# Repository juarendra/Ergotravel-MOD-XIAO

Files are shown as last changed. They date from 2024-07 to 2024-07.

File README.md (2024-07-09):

# Ergotravel-MOD-XIAO
This is MOD of Ergotravel, the normal redox for qmk and wired. This mod is for mod ergotravel to become wireless using ZMK Firmware, and add Swith and Battery socket

## Spesification
- Controller using Seeed Studio XIAO nRF52840 
- ZMK Firmware
- Battery Socket and Switch
- BLE Support
- Hotswap Switch
- 54 Keys

## Preview Hardware

<p align="center">
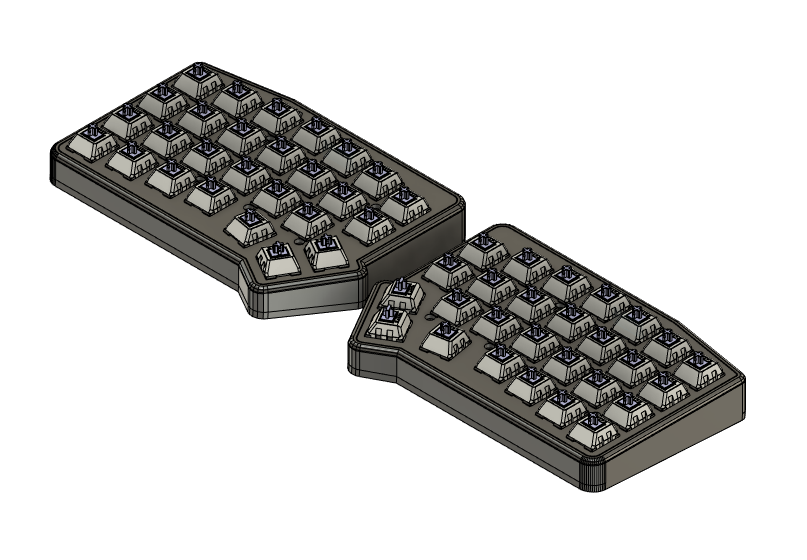
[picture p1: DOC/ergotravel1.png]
  
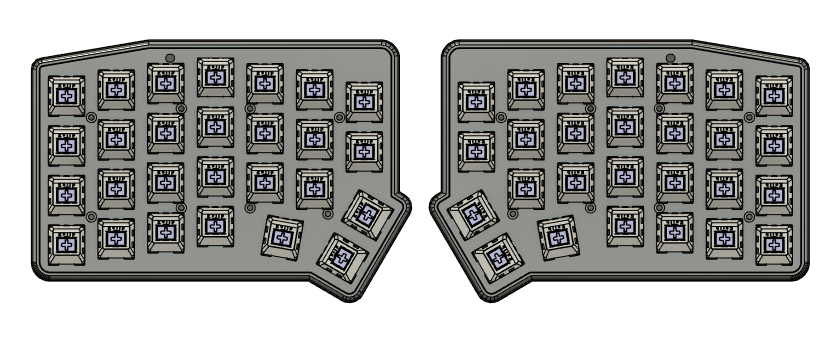
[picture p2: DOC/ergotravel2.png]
  
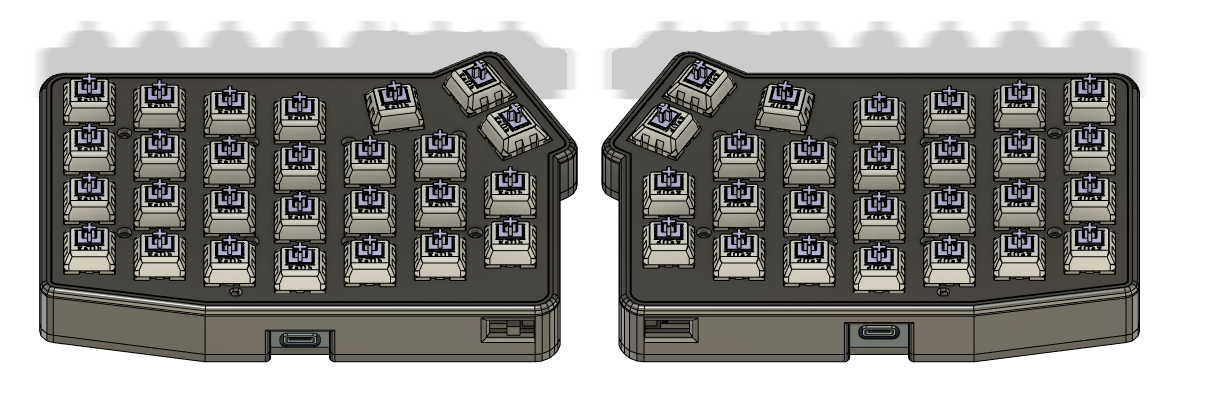
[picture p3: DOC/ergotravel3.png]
  
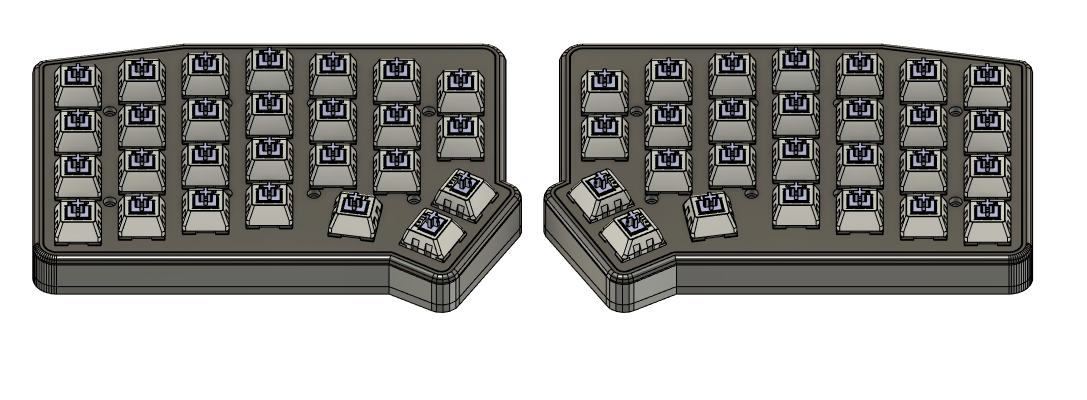
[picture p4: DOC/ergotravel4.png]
  
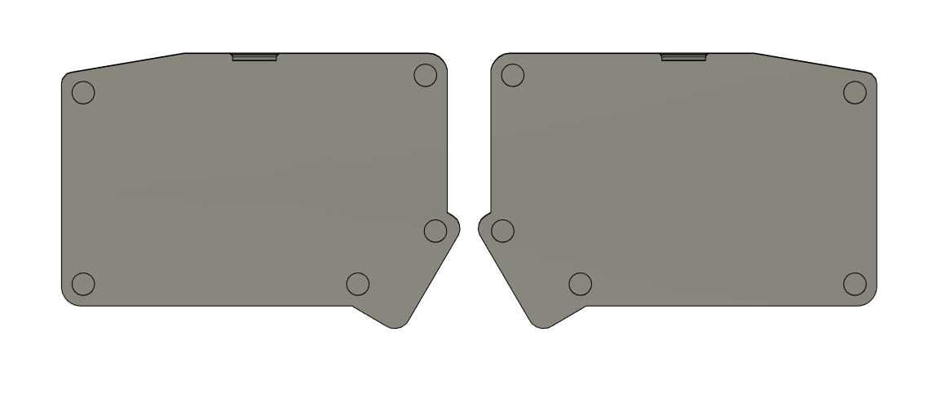
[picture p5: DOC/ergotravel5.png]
  

</p>

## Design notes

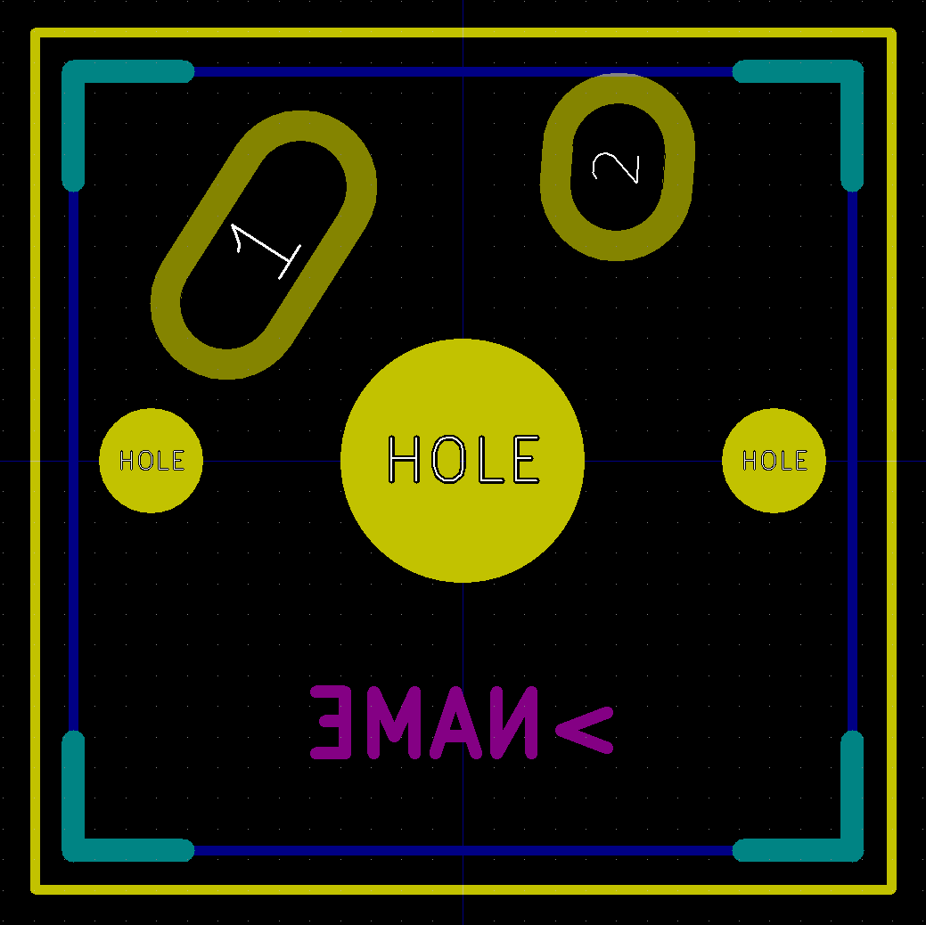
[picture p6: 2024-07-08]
HARDWARE/SCH-PCB/keebs.pretty-master/img/Mx_Alps_100.png

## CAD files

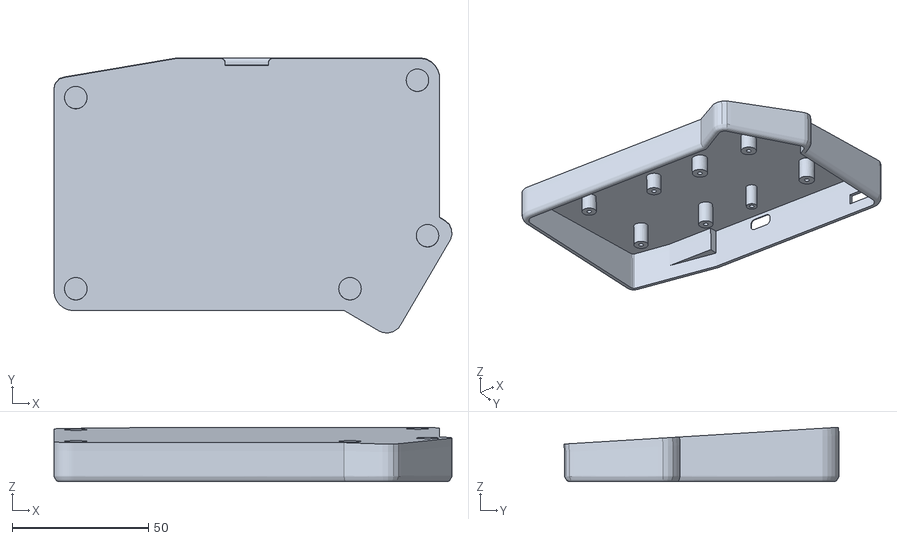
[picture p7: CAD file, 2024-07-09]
HARDWARE/3D/CASE/ERGOTRAVEL_MOD_BODY_KANAN.stl
146.0 x 100.9 x 20.0

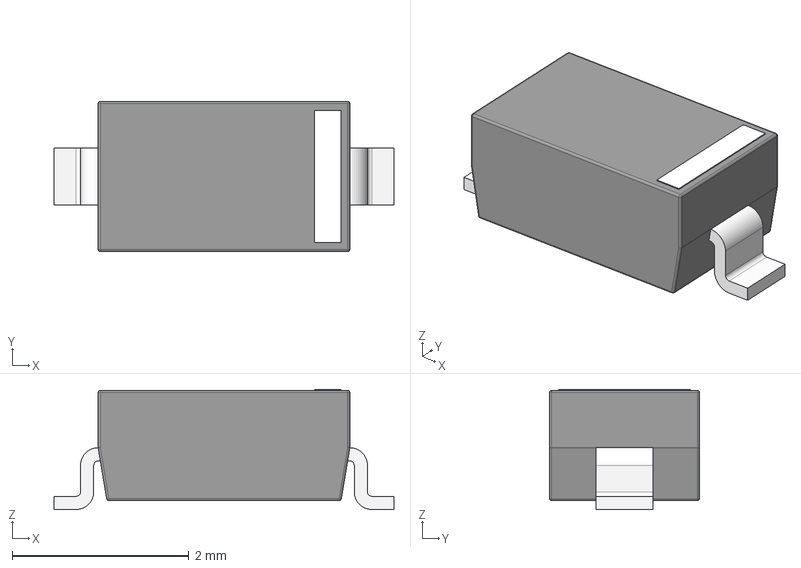
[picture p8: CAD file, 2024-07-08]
HARDWARE/SCH-PCB/3d/SOD-123.step
3.85 x 1.70 x 1.36 mm

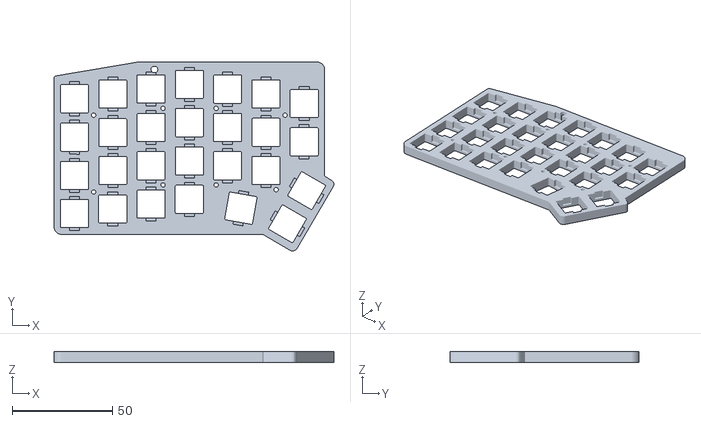
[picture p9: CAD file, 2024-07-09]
HARDWARE/3D/CASE/ERGOTRAVEL_MOD_PLATE_KANAN.stl
139.4 x 94.1 x 5.23

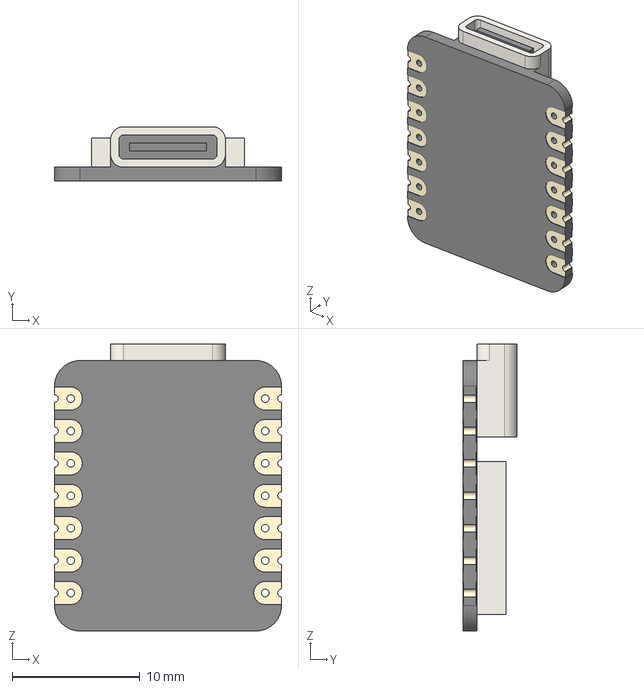
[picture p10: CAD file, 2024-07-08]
HARDWARE/SCH-PCB/3d/Seeeduino Xiao.step
17.8 x 4.27 x 22.5 mm

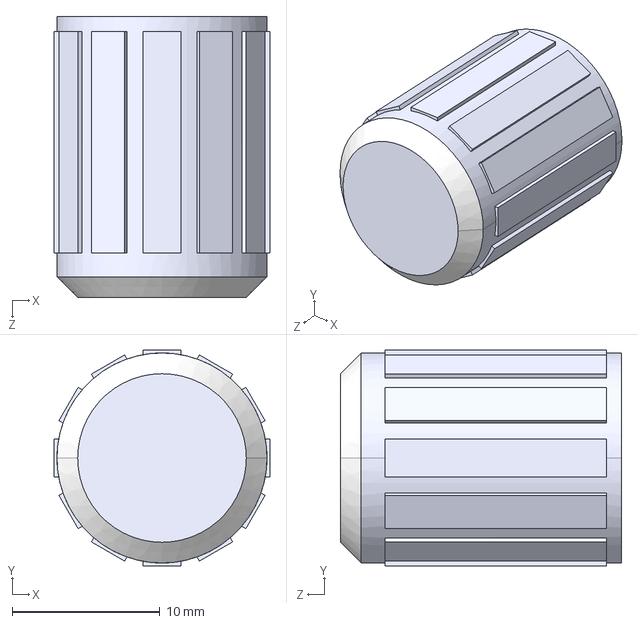
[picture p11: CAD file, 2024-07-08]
HARDWARE/SCH-PCB/models/RotaryEncKnob.STEP
14.6 x 14.6 x 19.0 mm

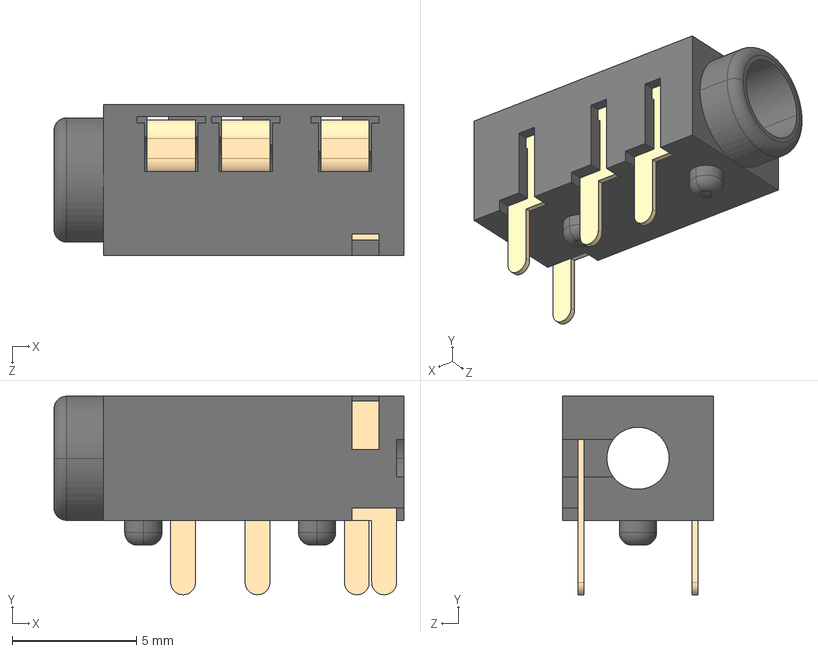
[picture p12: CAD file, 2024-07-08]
HARDWARE/SCH-PCB/3d/PJ320A.STEP
14.1 x 8.00 x 6.10 mm
PJ320A蝶褲
PJ320A-Pin-A x 3
PJ320A-Pin-B

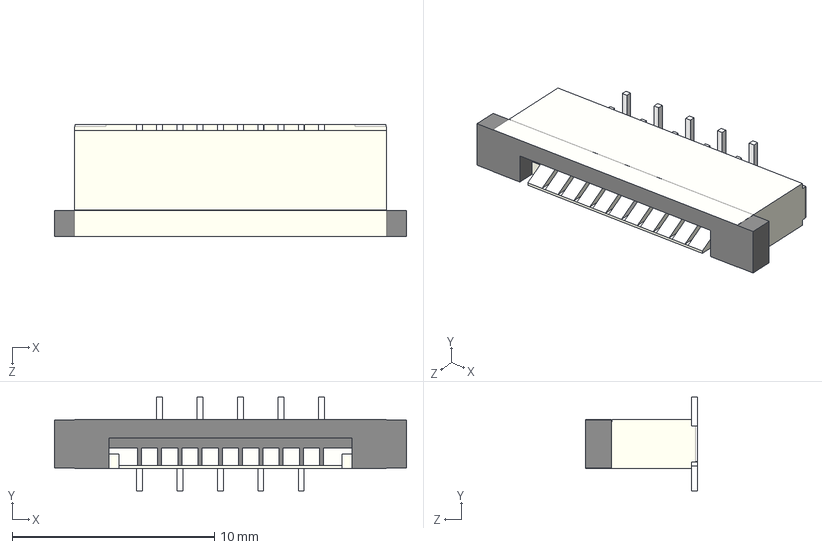
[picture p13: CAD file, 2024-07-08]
HARDWARE/SCH-PCB/models/FPC vertical connector-1mm-10PIN.STEP
17.4 x 4.64 x 5.55 mm

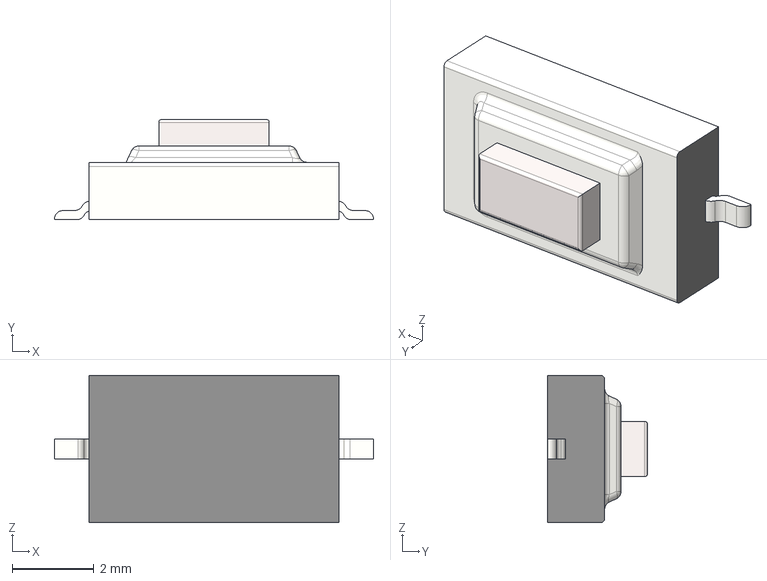
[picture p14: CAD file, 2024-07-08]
HARDWARE/SCH-PCB/3d/TactileButton(6x3,5mm)_SMD.stp
7.80 x 2.45 x 3.60 mm

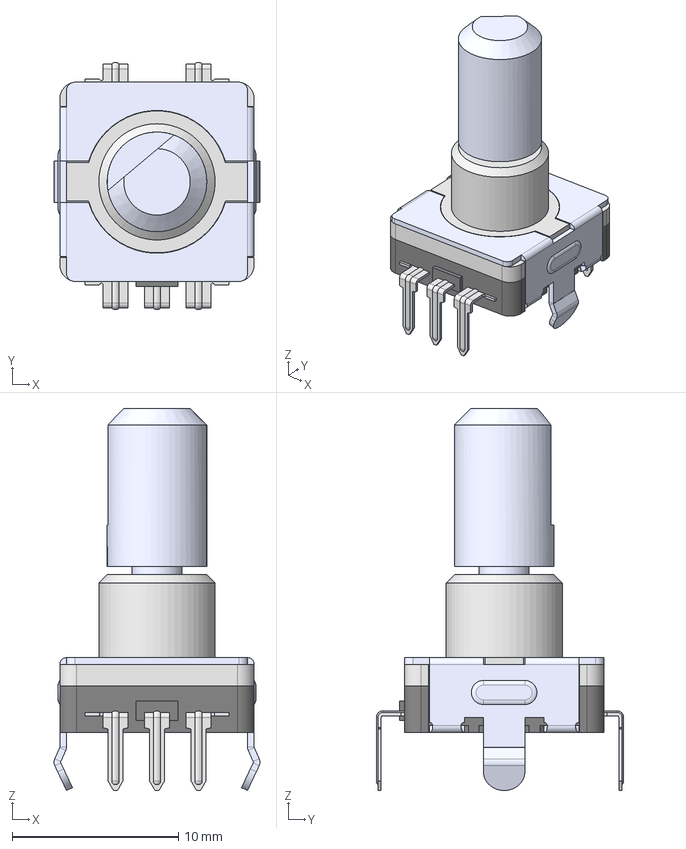
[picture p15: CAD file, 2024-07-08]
HARDWARE/SCH-PCB/models/EC11-THT-15F-black.step
12.4 x 14.9 x 23.0 mm
Lb5
15F
EC11-Housing-THT

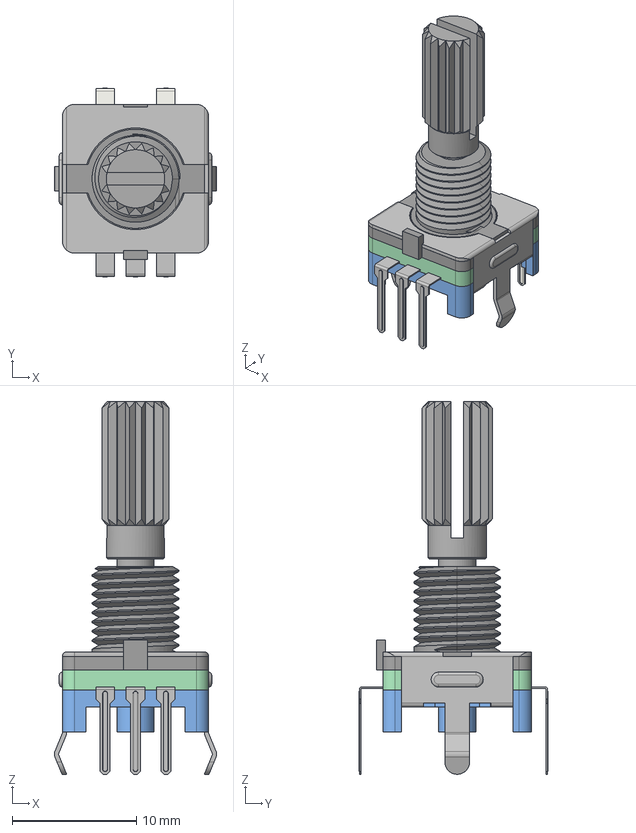
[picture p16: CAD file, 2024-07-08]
HARDWARE/SCH-PCB/3d/EC11_Rotary_Encoder_Switched.step
13.1 x 15.3 x 30.1 mm

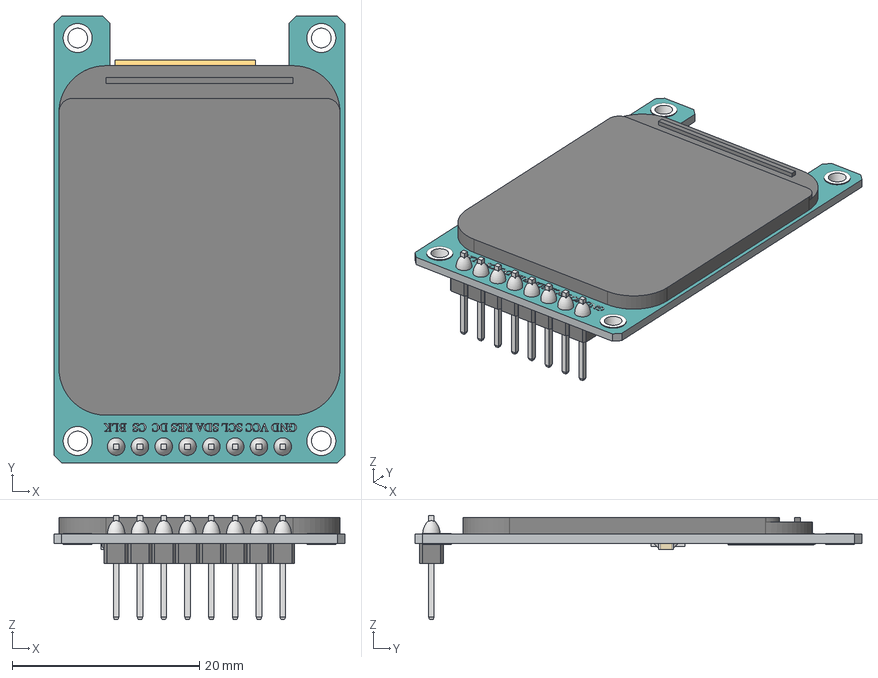
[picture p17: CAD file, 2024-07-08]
HARDWARE/SCH-PCB/models/Display 1.69 ST7789V2.step
31.0 x 47.7 x 11.1 mm
PCB
Display
Pin x 8
R-0603 x 3
C-0603 x 2
U-0603

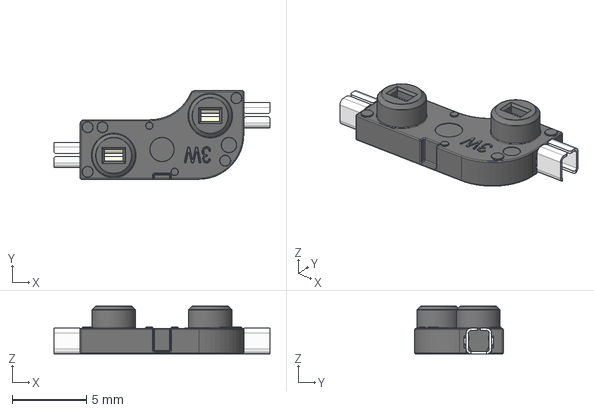
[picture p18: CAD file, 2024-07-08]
HARDWARE/SCH-PCB/3d/Kailh Hotswap MX v22.step
14.5 x 5.95 x 3.22 mm

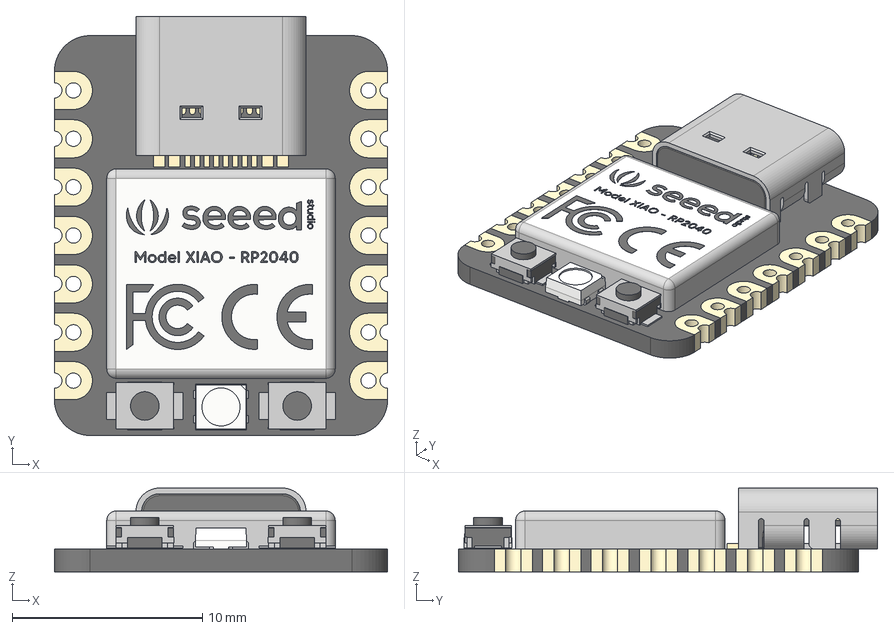
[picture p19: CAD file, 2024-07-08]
HARDWARE/SCH-PCB/models/Seeed Studio XIAO RP2040 v26.step
17.5 x 22.0 x 4.40 mm
type-c v2
smd_button v3
DOUT
DIN
VSS
VDD
smd_button v3(Mirror)

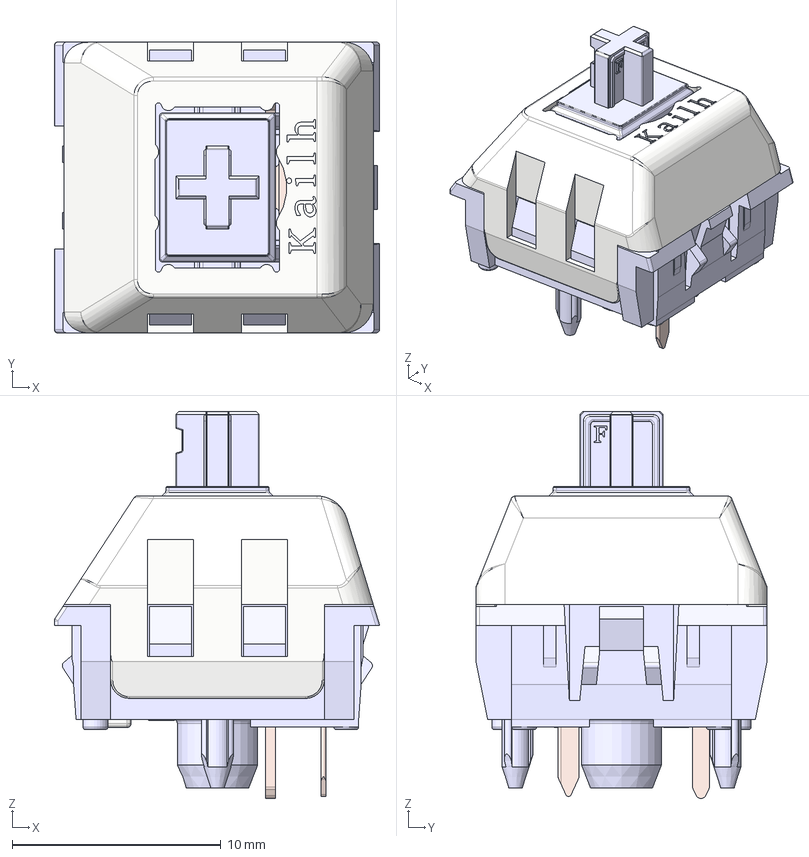
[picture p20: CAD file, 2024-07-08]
HARDWARE/SCH-PCB/3d/Kailh Polia.step
15.6 x 14.0 x 18.5 mm
Housing
ThickContact
SpringContact
Stem
Lid

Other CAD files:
HARDWARE/3D/CASE/ERGOTRAVEL_MOD_BODY_KIRI.stl
HARDWARE/3D/CASE/ERGOTRAVEL_MOD_PLATE_KIRI.stl
HARDWARE/SCH-PCB/models/PG1350-socket.STEP
HARDWARE/SCH-PCB/models/TM040040_Overlay.STEP

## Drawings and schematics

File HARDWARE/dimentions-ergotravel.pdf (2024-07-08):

74.27

100.89 145.49 18.219.98 13.88 | 29.89 24.08 | A | USB Type C | A (1:0.3) 16

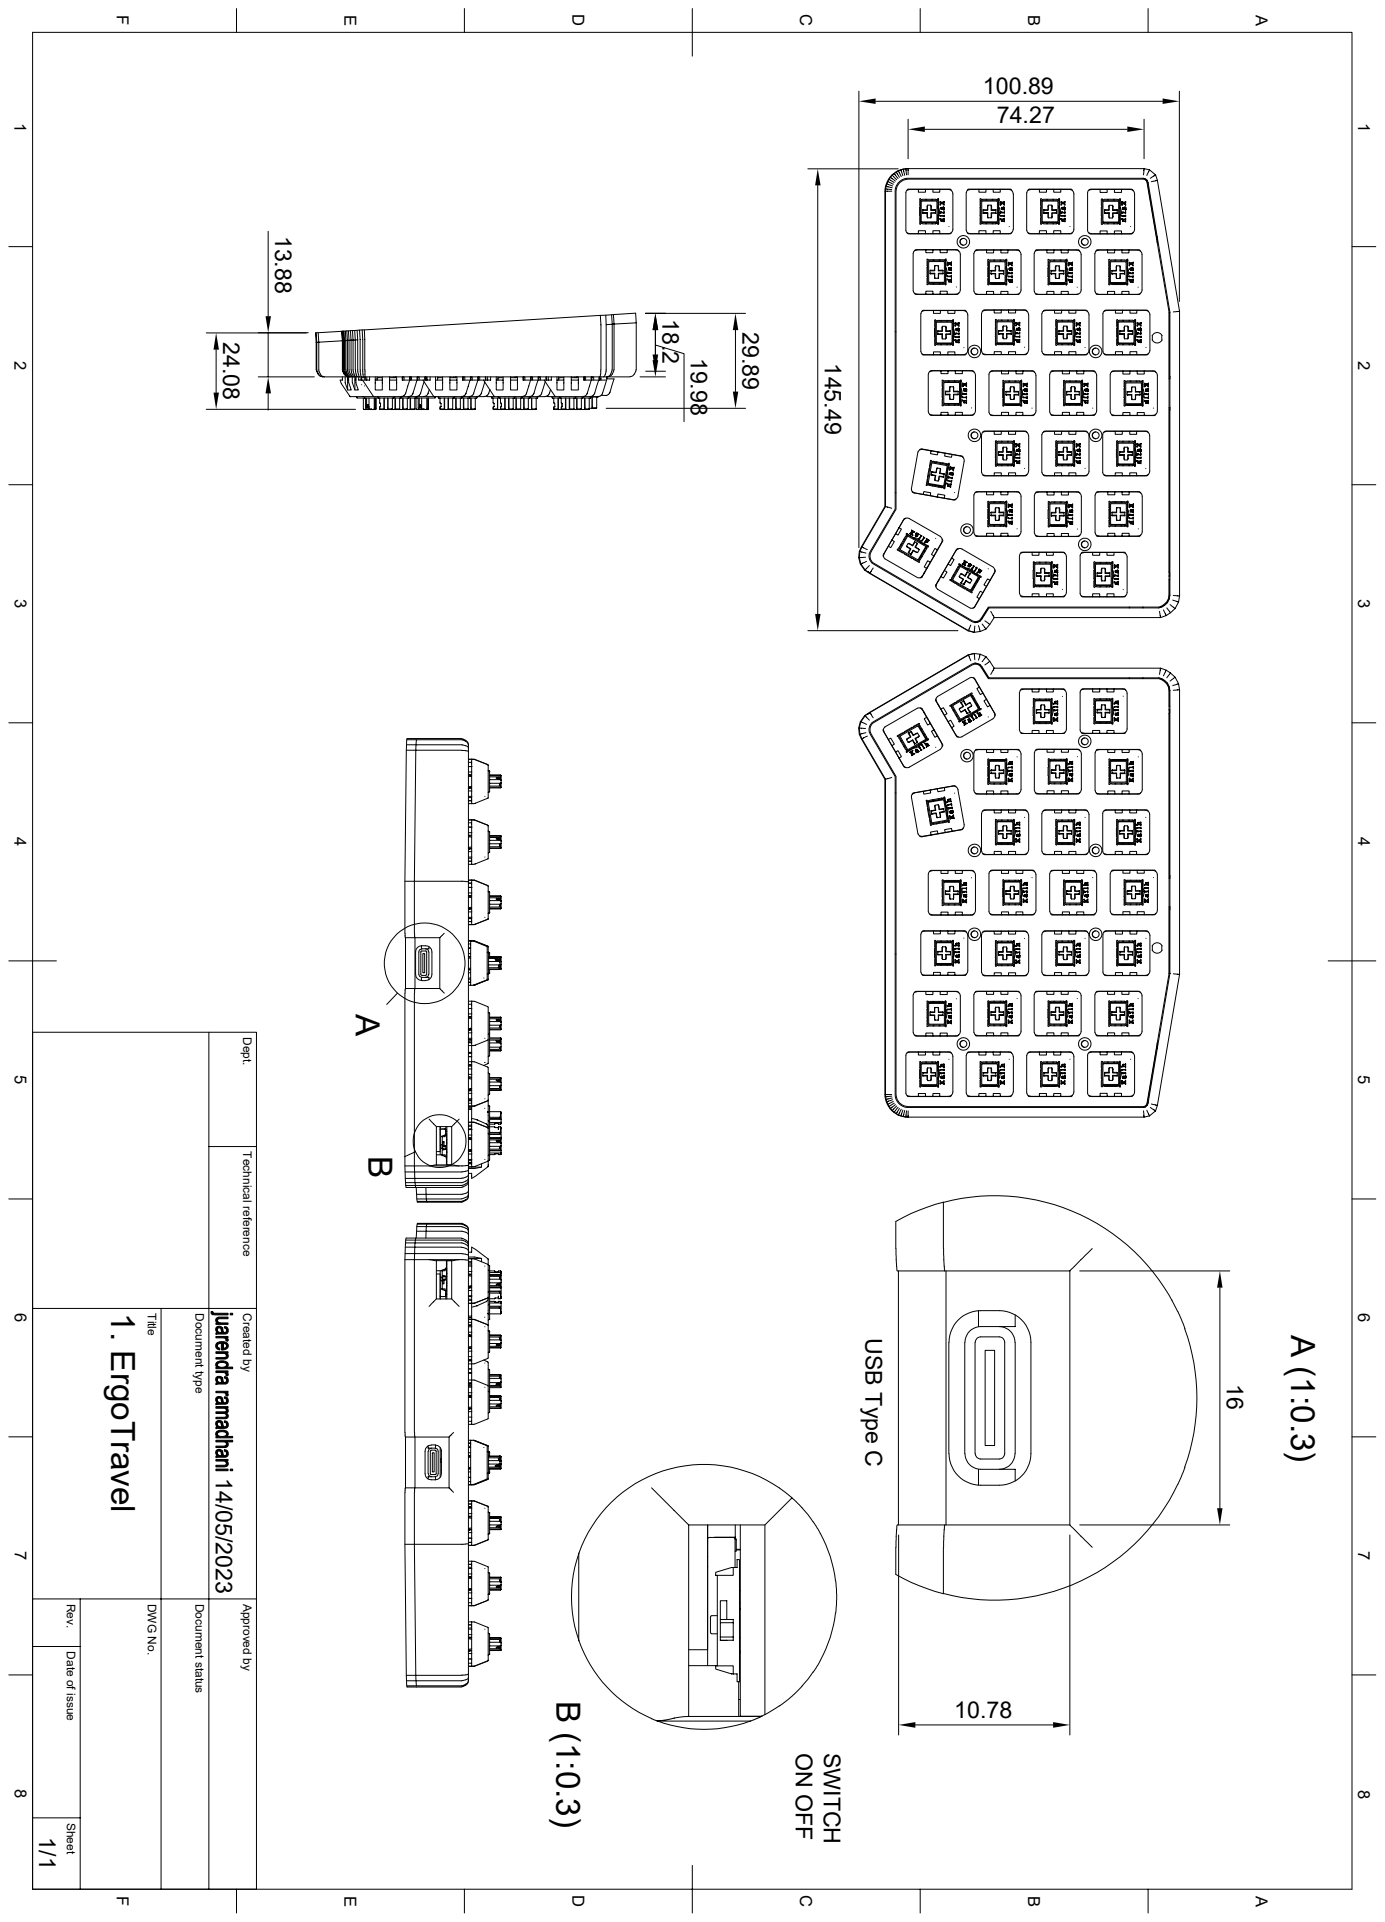
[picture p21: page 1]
ON OFF SWITCH

1 A 2 3 4 5 6 7 8 1 2 3 4 5 6 7 8 FEDCB FEDCBA Dept. Technical reference Created by Approved by Title DWG No. Document type Document status Rev. Date of issue Sheet 14/05/2023 1/1 1. ErgoTravel

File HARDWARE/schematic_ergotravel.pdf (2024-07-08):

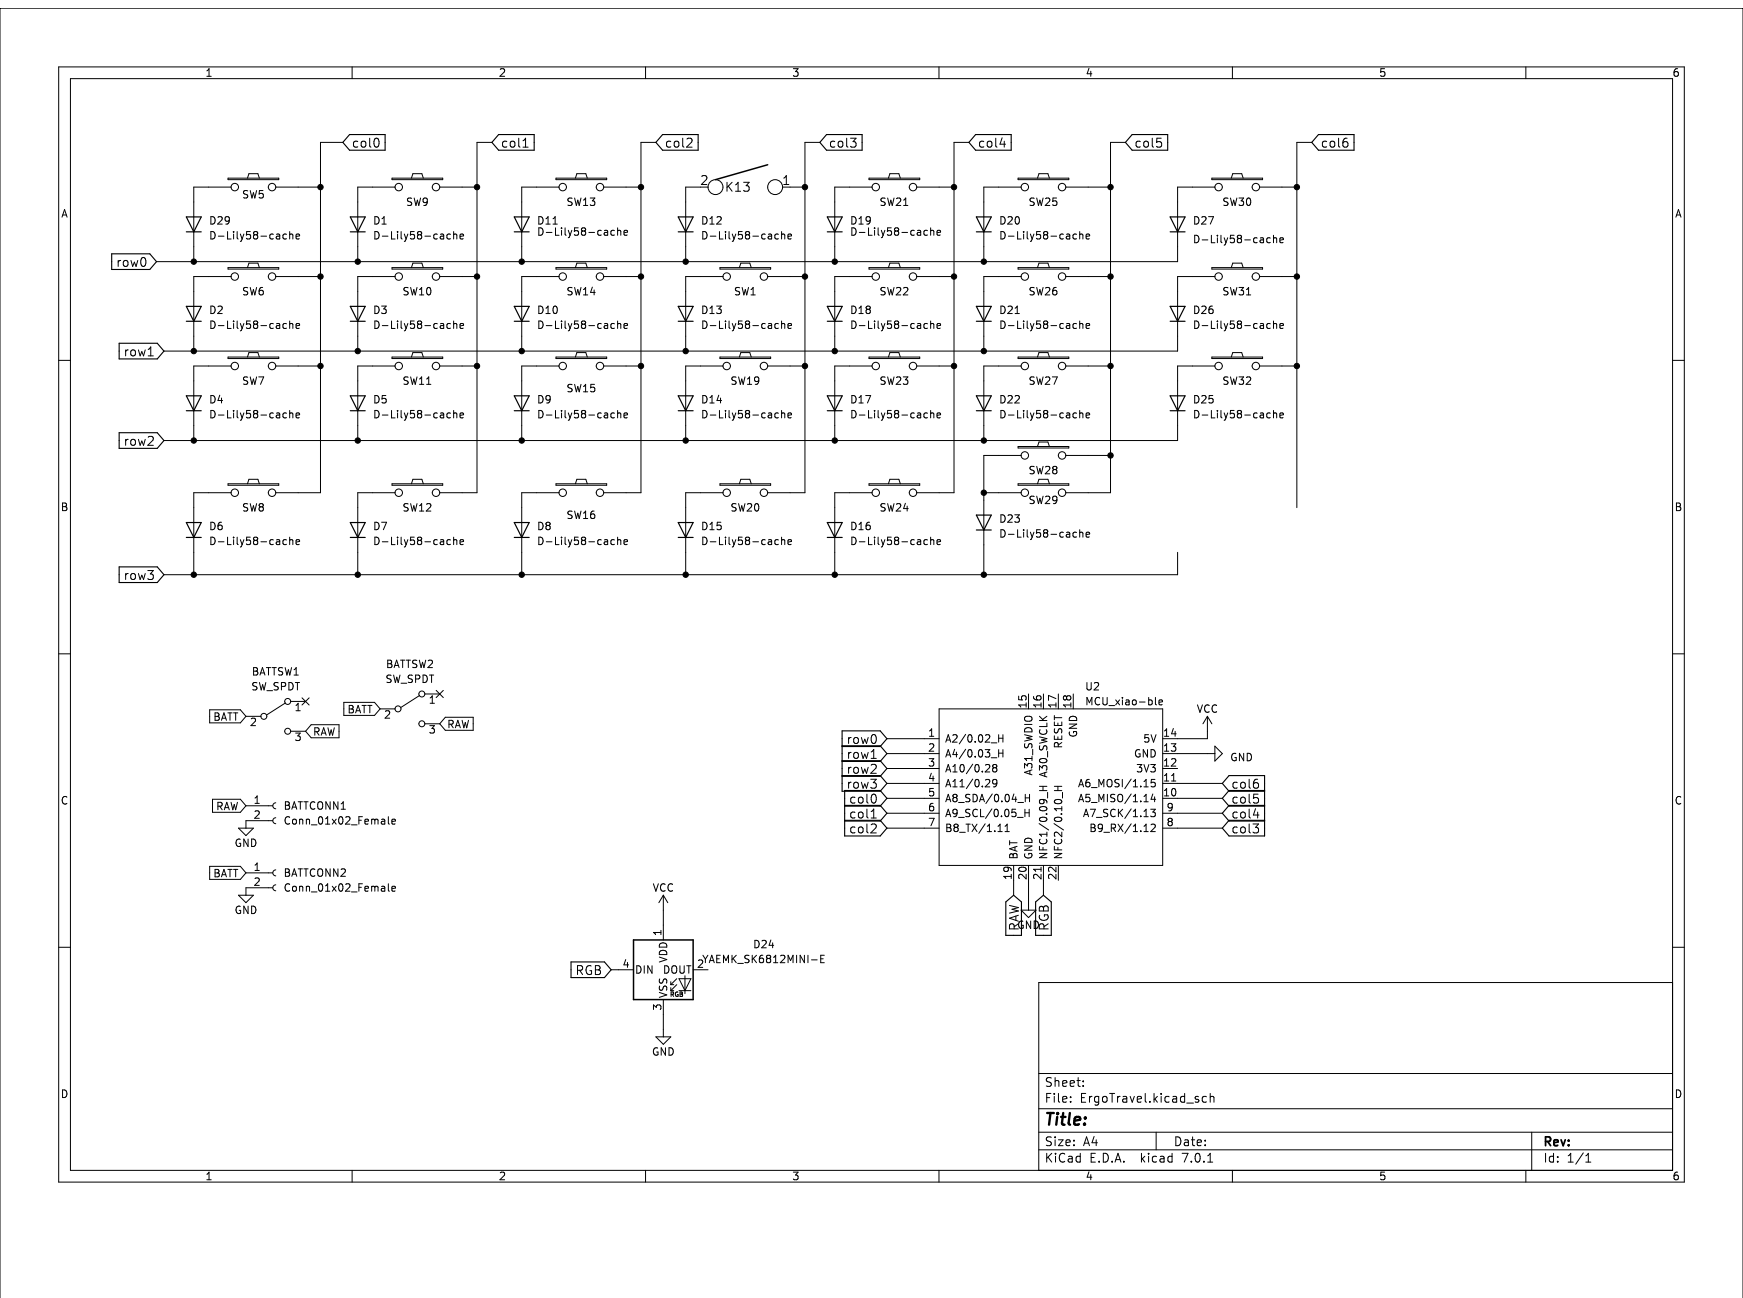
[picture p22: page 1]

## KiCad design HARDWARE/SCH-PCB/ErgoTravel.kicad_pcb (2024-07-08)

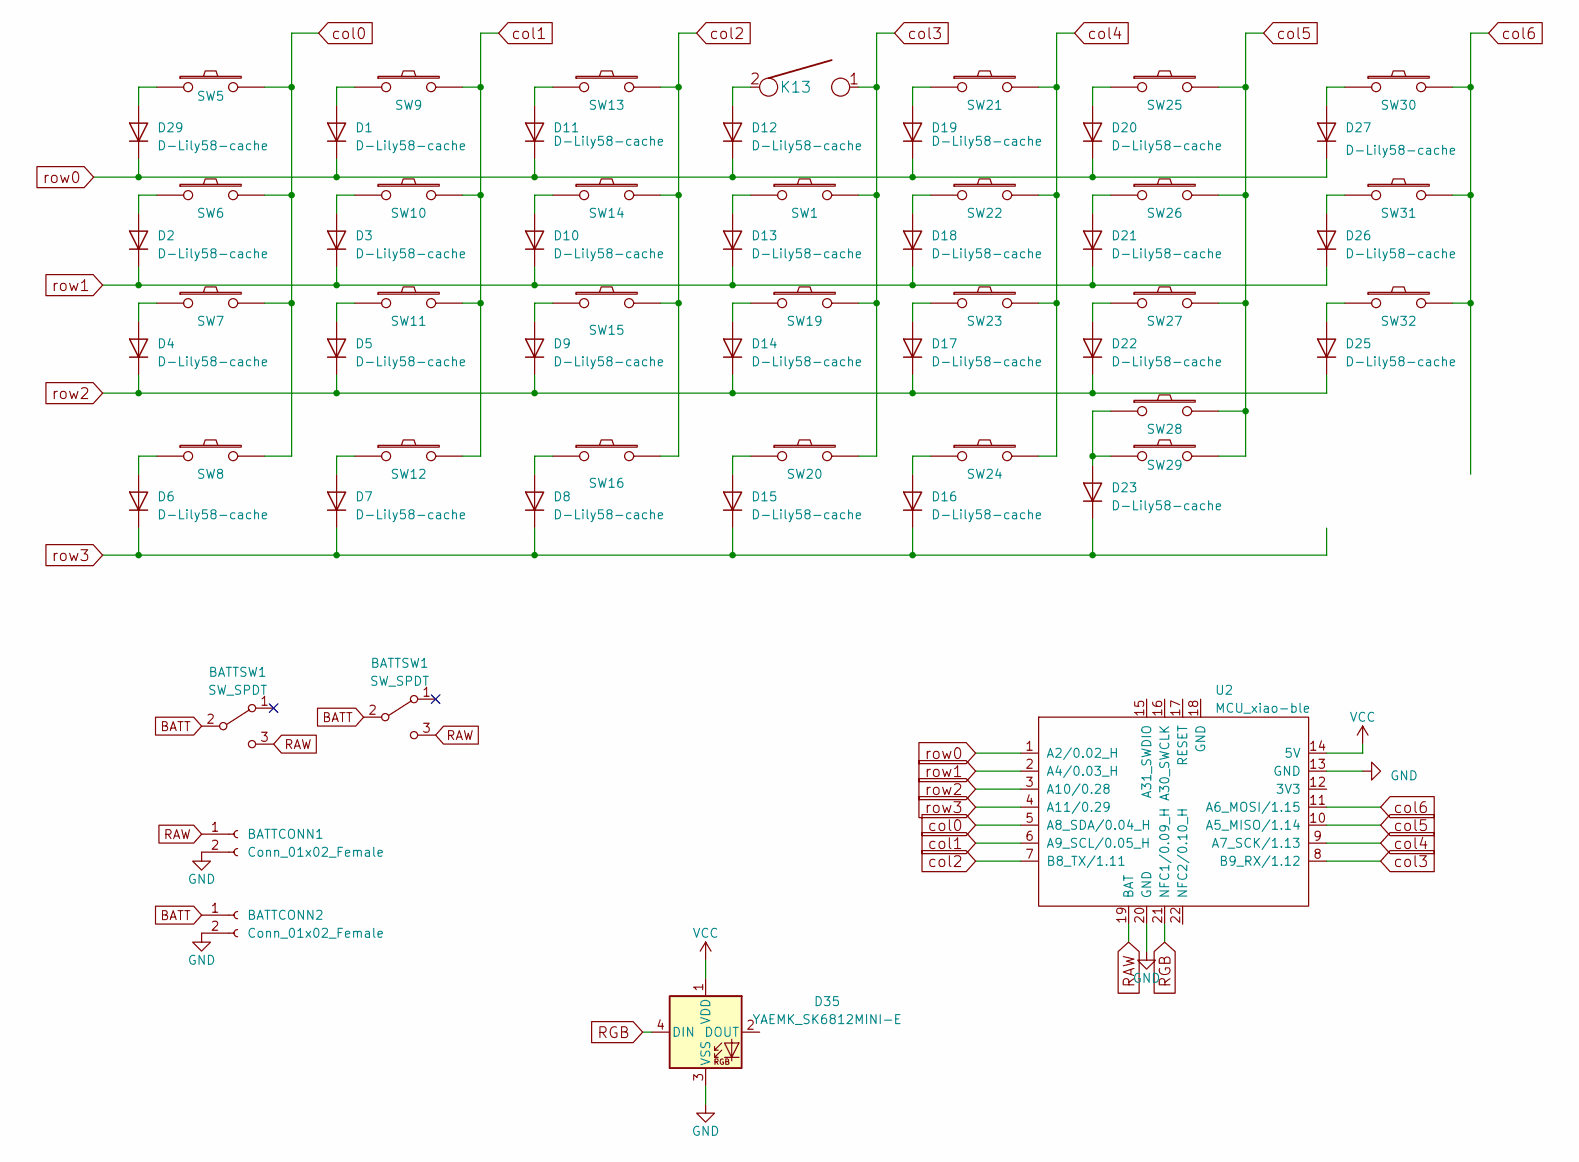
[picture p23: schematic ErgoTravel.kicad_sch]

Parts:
BATTCONN1, BATTCONN2: Conn_01x02_Female; Connector_JST-1x02-2.00mm
BATTSW1: SW_SPDT; Switch_SPDT-PCM12
D1, D2, D3, D4, D5, D6, D7, D8, D9, D10, D11, D12, D13, D14, D15, D16, D17, D18, D19, D20, D21, D22, D23, D25, D26, D27, D29: D-Lily58-cache; Diode_SOD123
D35: YAEMK_SK6812MINI-E; SK6812_mini_e_flipable
K13: KEYSW; SW_MX_reversible
SW1, SW5, SW6, SW7, SW8, SW9, SW10, SW11, SW12, SW13, SW14, SW15, SW16, SW19, SW20, SW21, SW22, SW23, SW24, SW25, SW26, SW27, SW28, SW29, SW30, SW31, SW32: SW_PUSH-Lily58-cache; CherryMX_Hotswap
U2: MCU_xiao-ble; MCU_xiao-ble-tht

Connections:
BATT: BATTCONN2.1, BATTSW1.2 (B); also elsewhere on the board
GND: BATTCONN1.2, BATTCONN2.2, U2.13 (GND), U2.20 (GND); also elsewhere on the board
unnamed: D1.2 (A), SW9.1
unnamed: D2.2 (A), SW6.1
unnamed: D3.2 (A), SW10.1
unnamed: D4.2 (A), SW7.1
unnamed: D5.2 (A), SW11.1
unnamed: D6.2 (A), SW8.1
unnamed: D7.2 (A), SW12.1
unnamed: D8.2 (A), SW16.1
unnamed: D9.2 (A), SW15.1
unnamed: D10.2 (A), SW14.1
unnamed: D11.2 (A), SW13.1
unnamed: D12.2 (A), K13.2
unnamed: D13.2 (A), SW1.1
unnamed: D14.2 (A), SW19.1
unnamed: D15.2 (A), SW20.1
unnamed: D16.2 (A), SW24.1
unnamed: D17.2 (A), SW23.1
unnamed: D18.2 (A), SW22.1
unnamed: D19.2 (A), SW21.1
unnamed: D20.2 (A), SW25.1
unnamed: D21.2 (A), SW26.1
unnamed: D22.2 (A), SW27.1
unnamed: D23.2 (A), SW28.1, SW29.1
unnamed: D25.2 (A), SW32.1
unnamed: D26.2 (A), SW31.1
unnamed: D27.2 (A), SW30.1
unnamed: D29.2 (A), SW5.1
RAW: BATTCONN1.1, BATTSW1.3 (C), U2.19 (BAT); also elsewhere on the board
RGB: U2.21 (NFC1/0.09_H); also elsewhere on the board
VCC: U2.14 (5V); also elsewhere on the board
col0: SW5.2, SW6.2, SW7.2, SW8.2, U2.5 (A8_SDA/0.04_H)
col1: SW9.2, SW10.2, SW11.2, SW12.2, U2.6 (A9_SCL/0.05_H)
col2: SW13.2, SW14.2, SW15.2, SW16.2, U2.7 (B8_TX/1.11)
col3: K13.1, SW1.2, SW19.2, SW20.2, U2.8 (B9_RX/1.12)
col4: SW21.2, SW22.2, SW23.2, SW24.2, U2.9 (A7_SCK/1.13)
col5: SW25.2, SW26.2, SW27.2, SW28.2, SW29.2, U2.10 (A5_MISO/1.14)
col6: SW30.2, SW31.2, SW32.2, U2.11 (A6_MOSI/1.15)
row0: D1.1 (K), D11.1 (K), D12.1 (K), D19.1 (K), D20.1 (K), D27.1 (K), D29.1 (K), U2.1 (A2/0.02_H)
row1: D2.1 (K), D3.1 (K), D10.1 (K), D13.1 (K), D18.1 (K), D21.1 (K), D26.1 (K), U2.2 (A4/0.03_H)
row2: D4.1 (K), D5.1 (K), D9.1 (K), D14.1 (K), D17.1 (K), D22.1 (K), D25.1 (K), U2.3 (A10/0.28)
row3: D6.1 (K), D7.1 (K), D8.1 (K), D15.1 (K), D16.1 (K), D23.1 (K), U2.4 (A11/0.29)

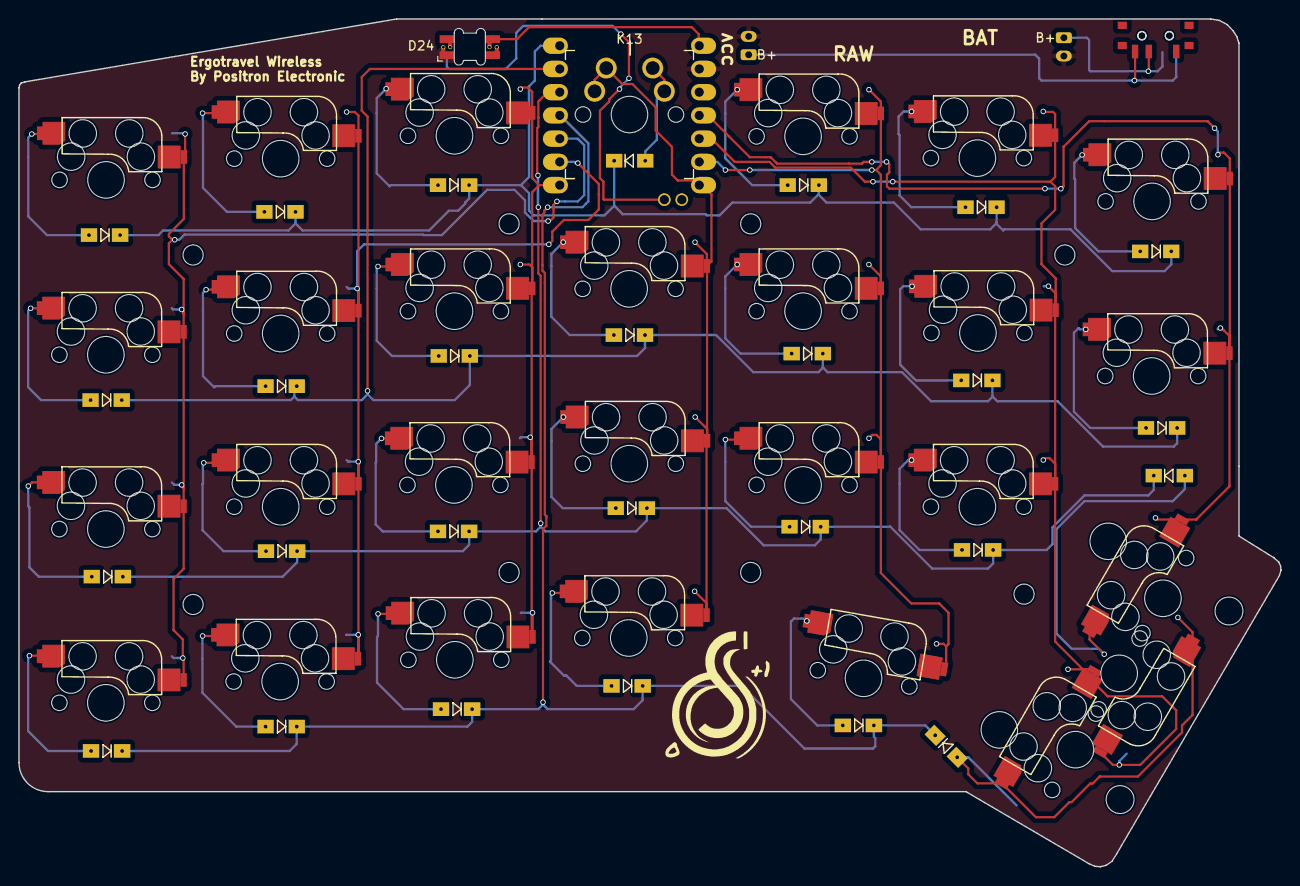
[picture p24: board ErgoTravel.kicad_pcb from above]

Board: 2 copper layers, 137.9 x 92.7 mm, 70 parts (1 on the bottom side), 43 nets.

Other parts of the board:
BATTSW2: SW_SPDT; Switch_SPDT-PCM12
D24: YAEMK_SK6812MINI-E; SK6812_mini_e_flipable
H1: MountingHole; Stabilizer_MX_2u
J5, J6, J7, J8, J9, J10, J11, J12: Conn_01x01; MountingHole_2.2mm_M2_DIN965

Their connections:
BATT: BATTSW2.2 (B); also elsewhere on the board
GND: D24.3 (VSS); also elsewhere on the board
RAW: BATTSW2.3 (C); also elsewhere on the board
RGB: D24.4 (DIN); also elsewhere on the board
VCC: D24.1 (VDD); also elsewhere on the board

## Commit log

2024-07-08 FEAT: add Hardware schematic
2024-07-09 FEAT: add 3d model and case
    [ERGOTRAVEL_MOD_BODY_KANAN.stl, ERGOTRAVEL_MOD_BODY_KIRI.stl, ERGOTRAVEL_MOD_PLATE_KANAN.stl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]
